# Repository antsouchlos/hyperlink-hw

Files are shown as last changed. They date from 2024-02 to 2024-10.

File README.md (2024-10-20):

# HyperLink

A PCB for gathering data form CommonSense boards over bluetooth and
retransmitting over wifi.

After cloning, the libraries can be downloaded using

```bash
$ git submodule update --init
```

## PCB




## Schematic



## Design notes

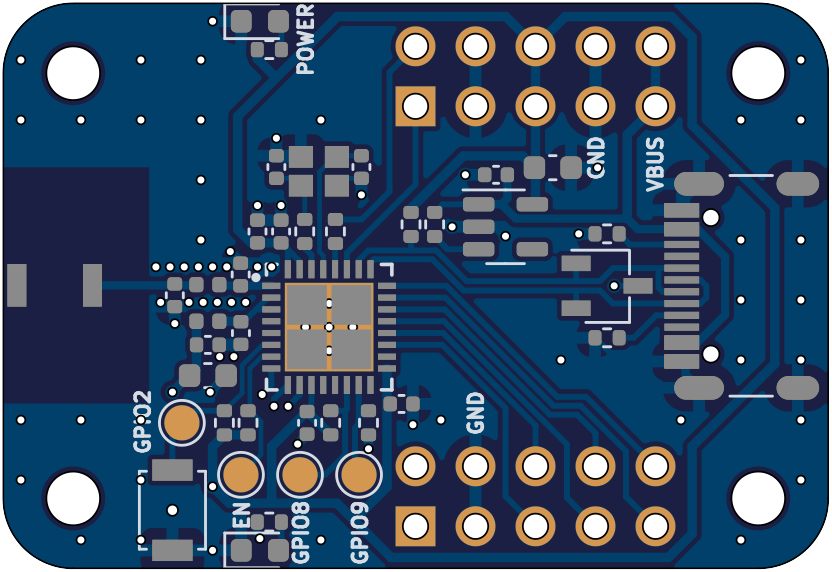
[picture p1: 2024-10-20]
doc/generated/HyperLink-top.png

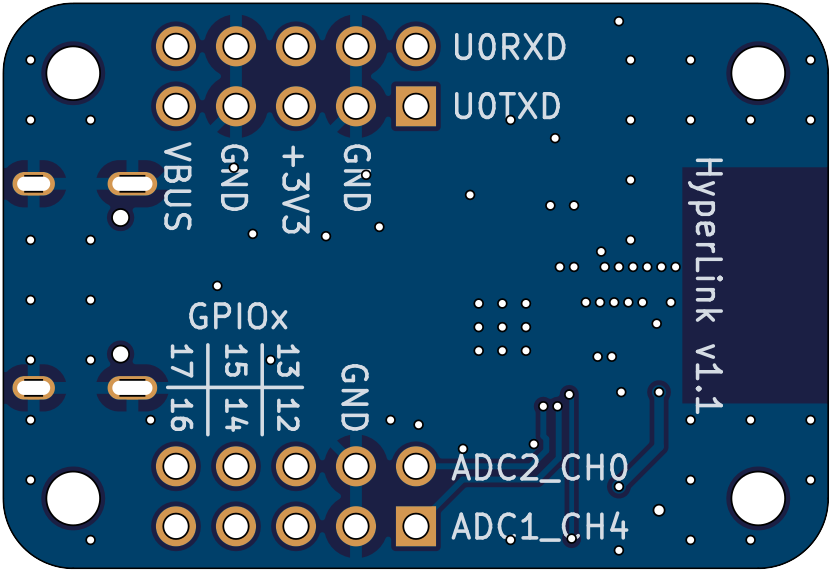
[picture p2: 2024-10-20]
doc/generated/HyperLink-bottom.png

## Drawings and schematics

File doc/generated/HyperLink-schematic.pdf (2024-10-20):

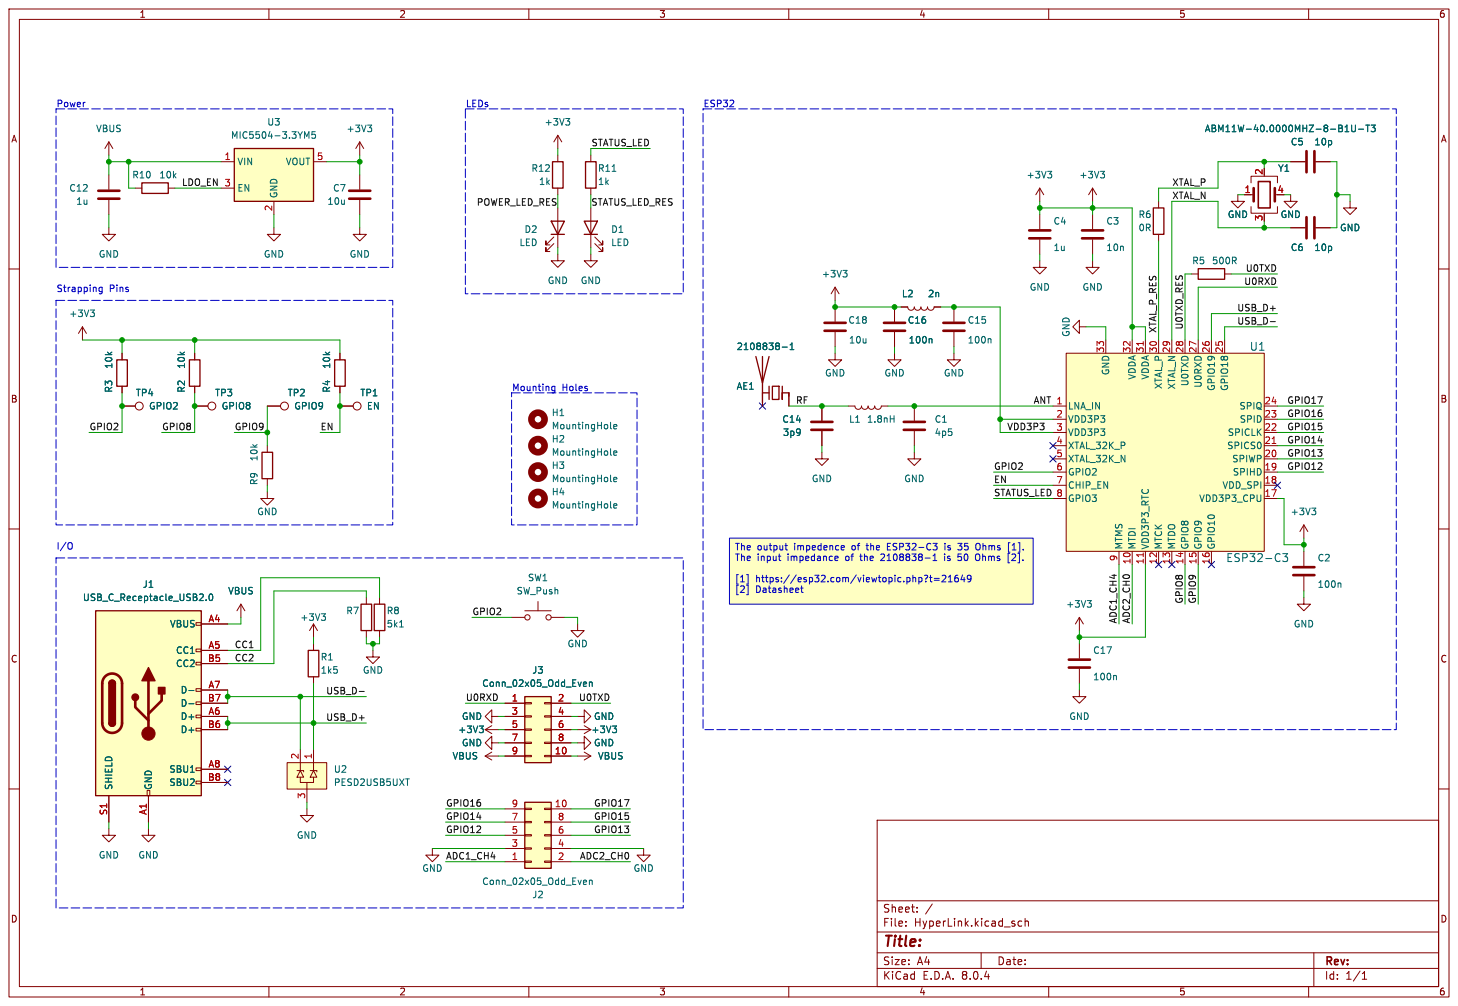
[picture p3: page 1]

2 EN 3 VOUT 5 U3 MIC5504-3.3YM5 H4 MountingHole H1 MountingHole H3 MountingHole H2 MountingHoleR11

[1] https://esp32.com/viewtopic.php?t=21649

Id: 1/1 Title: File: HyperLink.kicad_sch Sheet: / GND

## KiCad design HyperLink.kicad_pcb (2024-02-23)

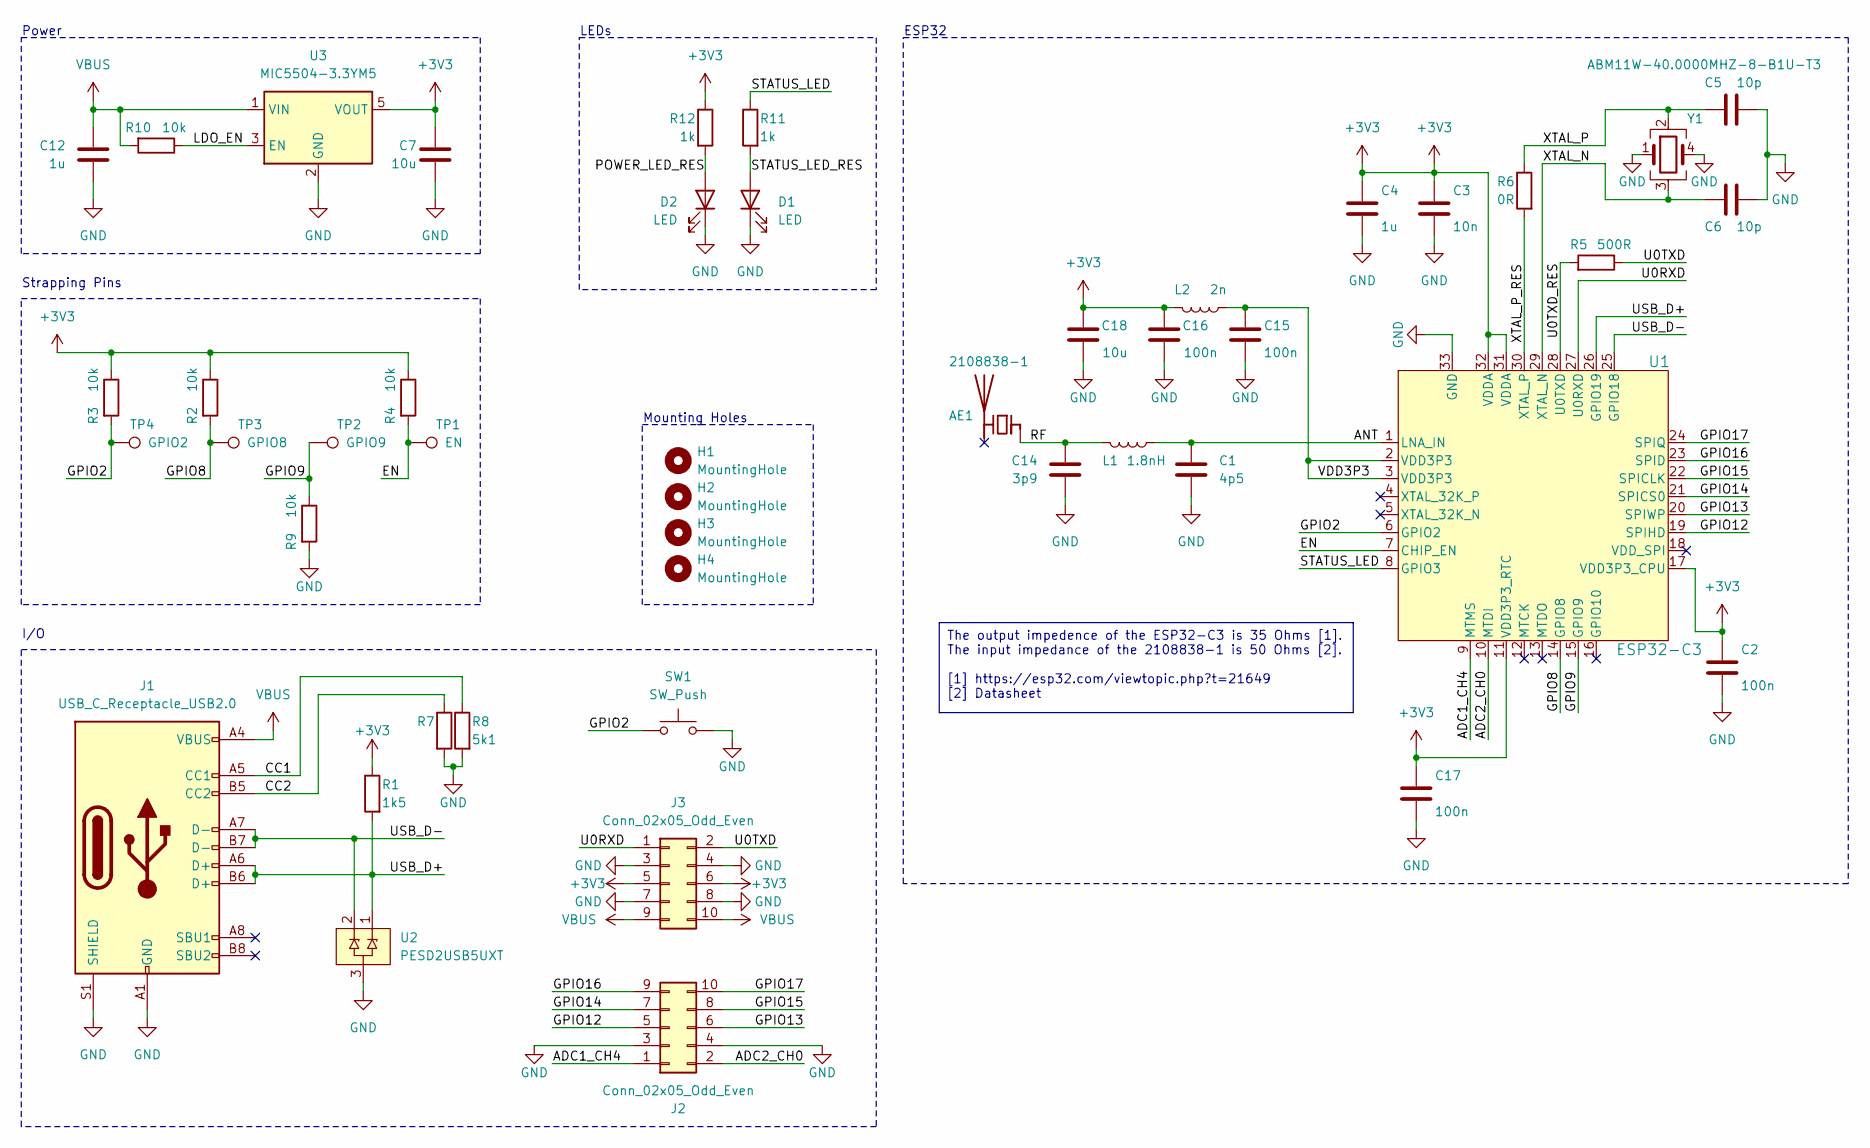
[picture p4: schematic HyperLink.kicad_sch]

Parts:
AE1: 2108838-1
C1: 4p5; C_0402_1005Metric
C2, C15, C16, C17: 100n; C_0402_1005Metric
C3: 10n; C_0402_1005Metric
C4, C12: 1u; C_0402_1005Metric
C5, C6: 10p; C_0402_1005Metric
C7, C18: 10u; C_0603_1608Metric
C14: 3p9; C_0402_1005Metric
D1, D2: LED; LED_0603_1608Metric
H1, H2, H3, H4: MountingHole; MountingHole_2.2mm_M2
J1: USB_C_Receptacle_USB2.0; USB4105-GF-A
J2, J3: Conn_02x05_Odd_Even; PinHeader_2x05_P2.54mm_Vertical
L1: 1.8nH; L_0402_1005Metric
L2: 2n; L_0402_1005Metric
R1: 1k5; R_0402_1005Metric
R2, R3, R4, R9, R10: 10k; R_0402_1005Metric
R5: 500R; R_0402_1005Metric
R6: 0R; R_0402_1005Metric
R7, R8: 5k1; R_0402_1005Metric
R11, R12: 1k; R_0402_1005Metric
SW1: SW_Push; SW_SPST_B3U-1000P
TP1: EN; TestPoint_Pad_D1.5mm
TP2: GPIO9; TestPoint_Pad_D1.5mm
TP3: GPIO8; TestPoint_Pad_D1.5mm
TP4: GPIO2; TestPoint_Pad_D1.5mm
U1: ESP32-C3; QFN32_5X5_EXP
U2: PESD2USB5UXT; TSOT-23
U3: MIC5504-3.3YM5; SOT-23-5
Y1: ABM11W-40.0000MHZ-8-B1U-T3; ABM11W-30.0000MHZ-7-D1X-T3

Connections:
+3V3: C2.1, C3.1, C4.1, C7.1, C16.1, C17.1, C18.1, J3.5, J3.6, L2.1, R1.1, R2.1, R3.1, R4.1, R12.1, U1.11 (VDD3P3_RTC), U1.17 (VDD3P3_CPU), U1.31 (VDDA), U1.32 (VDDA), U3.5 (VOUT)
/ADC1_CH4: J2.1, U1.9 (MTMS)
/ADC2_CH0: J2.2, U1.10 (MTDI)
/ANT: C1.1, L1.2, U1.1 (LNA_IN)
/CC1: J1.A5 (CC1), R8.1
/CC2: J1.B5 (CC2), R7.1
/EN: R4.2, TP1.1, U1.7 (CHIP_EN)
/GPIO2: R3.2, SW1.2, TP4.1, U1.6 (GPIO2)
/GPIO8: R2.2, TP3.1, U1.14 (GPIO8)
/GPIO9: R9.1, TP2.1, U1.15 (GPIO9)
/GPIO12: J2.5, U1.19 (SPIHD)
/GPIO13: J2.6, U1.20 (SPIWP)
/GPIO14: J2.7, U1.21 (SPICS0)
/GPIO15: J2.8, U1.22 (SPICLK)
/GPIO16: J2.9, U1.23 (SPID)
/GPIO17: J2.10, U1.24 (SPIQ)
/LDO_EN: R10.1, U3.3 (EN)
/POWER_LED_RES: D2.2 (A), R12.2
/RF: AE1.1 (FEED), C14.1, L1.1
/STATUS_LED: R11.1, U1.8 (GPIO3)
/STATUS_LED_RES: D1.2 (A), R11.2
/U0RXD: J3.1, U1.27 (U0RXD)
/U0TXD: J3.2, R5.1
/U0TXD_RES: R5.2, U1.28 (U0TXD)
/USB_D+: J1.A6 (D+), J1.B6 (D+), R1.2, U1.26 (GPIO19), U2.1
/USB_D-: J1.A7 (D-), J1.B7 (D-), U1.25 (GPIO18), U2.2
/VDD3P3: C15.1, L2.2, U1.2 (VDD3P3), U1.3 (VDD3P3)
/XTAL_N: C6.1, U1.29 (XTAL_N), Y1.3
/XTAL_P: C5.1, R6.1, Y1.2
/XTAL_P_RES: R6.2, U1.30 (XTAL_P)
GND: C1.2, C2.2, C3.2, C4.2, C5.2, C6.2, C7.2, C12.2, C14.2, C15.2, C16.2, C17.2, C18.2, D1.1 (K), D2.1 (K), J1.A1 (GND), J1.A12 (GND), J1.B1 (GND), J1.B12 (GND), J1.S1 (SHIELD), J2.3, J2.4, J3.3, J3.4, J3.7, J3.8, R7.2, R8.2, R9.2, SW1.1, U1.33 (GND), U2.3, U3.2 (GND), Y1.1, Y1.4
VBUS: C12.1, J1.A4 (VBUS), J1.A9 (VBUS), J1.B4 (VBUS), J1.B9 (VBUS), J3.9, J3.10, R10.2, U3.1 (VIN)

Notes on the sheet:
The output impedence of the ESP32-C3 is 35 Ohms [1]. The input impedance of the 2108838-1 is 50 Ohms [2]. [1] https://esp32.com/viewtopic.php?t=21649 [2] Datasheet
ESP32
I/O
Mounting Holes
Power
Strapping Pins
LEDs

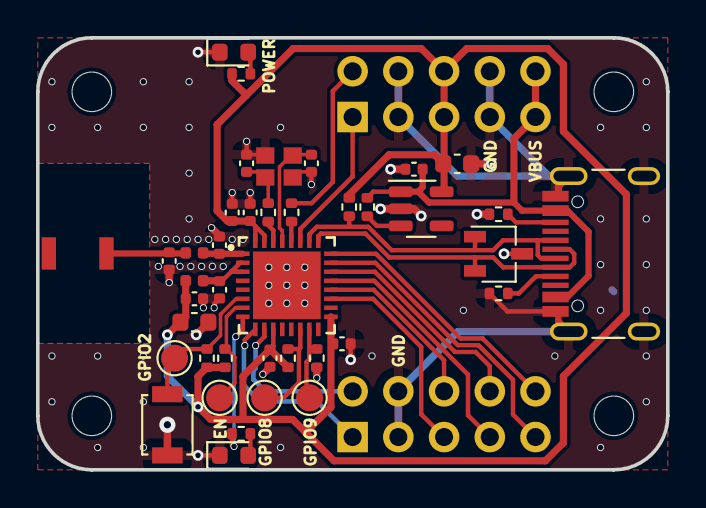
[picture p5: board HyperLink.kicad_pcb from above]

Board: 2 copper layers, 35.0 x 24.0 mm, 46 parts (0 on the bottom side), 32 nets.

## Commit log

2023-08-02 Copy stuff from other pc
    [IrrationaLink.kicad_pcb, IrrationaLink.kicad_sch]
2023-08-03 Add gitignore; Route USB lines
    [IrrationaLink.kicad_pcb, IrrationaLink.kicad_sch]
2023-08-07 Design first version of board (Crystal not routed yet)
    [IrrationaLink.kicad_pcb, IrrationaLink.kicad_sch]
2023-08-07 Remove board name; Minor other changes
    [IrrationaLink.kicad_pcb]
2023-08-07 Add button; Move power lines
    [IrrationaLink.kicad_pcb, IrrationaLink.kicad_sch]
2023-08-07 Move shield resistor and cap to front
    [IrrationaLink.kicad_pcb]
2023-08-07 Connect Crystal; Add 500R resistor to U0TXD
    [IrrationaLink.kicad_pcb, IrrationaLink.kicad_sch]
2023-08-07 Connect all shield pads
    [IrrationaLink.kicad_pcb]
2023-08-07 Add via stitching
    [IrrationaLink.kicad_pcb]
2023-08-07 Add USB pullups/downs and clean up schematic
    [IrrationaLink.kicad_sch]
2023-08-07 Add USB resistors to PCB
    [IrrationaLink.kicad_pcb, IrrationaLink.kicad_sch]
2023-08-09 Rename project
    [HyperLink.kicad_pcb, HyperLink.kicad_sch]
2023-08-09 Add TODOs to schematic
    [HyperLink.kicad_sch]
2023-08-22 Replace LDO and add USB TVS diode
    [HyperLink.kicad_pcb, HyperLink.kicad_sch]
2023-08-22 Add status LEDs
    [HyperLink.kicad_pcb, HyperLink.kicad_sch]
2023-08-22 Clean up schematic
    [HyperLink.kicad_sch]
2023-08-22 Tie SHIELD directly to GND
    [HyperLink.kicad_pcb, HyperLink.kicad_sch]
2023-08-22 Fix last remaining TODOs and clean up schematic
    [HyperLink.kicad_pcb, HyperLink.kicad_sch]
2023-08-22 Replace Antenna symbol with chip antenna
    [HyperLink.kicad_pcb, HyperLink.kicad_sch]
2023-08-26 Remove 'F' from capacitor values
    [HyperLink.kicad_sch]
2023-09-13 Flip D+ and D- at connector
    [HyperLink.kicad_pcb, HyperLink.kicad_sch]
2023-09-13 Change connector thermal reliefs, various vias
    [HyperLink.kicad_pcb]
2023-09-13 Update crystal footprint
    [HyperLink.kicad_pcb]
2023-09-13 Replace unnecessarily thick traces with thinner ones
    [HyperLink.kicad_pcb]
2023-09-13 Move status LED
    [HyperLink.kicad_pcb, HyperLink.kicad_sch]
2023-09-13 Add silk screen text
    [HyperLink.kicad_pcb]
2023-09-13 Check out new version of library and replace usb connector footprint
    [HyperLink.kicad_pcb, HyperLink.kicad_sch]
2023-11-18 Change cap values
    [HyperLink.kicad_sch]
2023-11-21 Fix matching network component values
    [HyperLink.kicad_pcb, HyperLink.kicad_sch]
2024-02-23 Add pulldown resistor to GPIO9 pin
    [HyperLink.kicad_pcb, HyperLink.kicad_sch]
